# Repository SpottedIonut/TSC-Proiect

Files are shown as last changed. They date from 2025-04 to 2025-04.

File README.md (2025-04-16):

#### Spirchez Mihai 331CA
## Block Diagram
```mermaid
graph TD
  %% Center
  ESP[<span style='color:#e0ccff'><b>ESP32</b></span>]

  %% SPI Devices (Top)
  NOR[<span style='color:#ffcccc'>External NOR Flash</span>]
  EPD[<span style='color:#ffcccc'>E-Paper Display</span>]
  SD[<span style='color:#ffcccc'>SD Card</span>]

  NOR -->|SPI| ESP
  ESP -->|SPI| EPD
  SD -->|SPI| ESP

  %% I2C Devices (Bottom)
  RTC[<span style='color:#cce5ff'>RTC Module</span>]
  ENV[<span style='color:#cce5ff'>Environmental Sensor</span>]
  BCL[<span style='color:#cce5ff'>Battery Charge Level</span>]

  RTC -->|I2C| ESP
  ENV -->|I2C| ESP
  BCL -->|I2C| ESP

  %% Buttons (Left)
  BTN[<span style='color:#d4f4dd'>Buttons</span>]
  BTN --> ESP

  %% USB and Power (Right)
  USB[USB C Connector]
  CHG[Charging Controller]
  REG[Voltage Regulator]
  BATT[Battery]

  ESP -->|USB| USB
  USB --> CHG
  USB --> REG
  BATT --> CHG
  BATT --> REG

```
## Bill of Materials
|Component|Description|Purchase|Datasheet|
|---|---|---|---|
|EAGLE-LTSPICE_CC0402 | Capacitor | https://eu.mouser.com/ProductDetail/KEMET/C0402C475K8PACTU?qs=ulEaXIWI0c9ebKRT3r3htg%3D%3D | https://eu.mouser.com/datasheet/2/447/KEM_C1006_X5R_SMD-3316465.pdf
|ESP32_WROVER_EAGLE-LTSPICE_RR0402 | Resistor | https://eu.mouser.com/ProductDetail/Vishay-Beyschlag/MCS04020D9101BE000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  | https://www.vishay.com/docs/28700/mcx0x0xpre.pdf
|RCL_CPOL-EUCT3528 | Capacitor | https://eu.mouser.com/ProductDetail/Nichicon/LGN2W101MELA25?qs=Fe64Qgzkstf1zMszMsgRoA%3D%3D | https://eu.mouser.com/datasheet/2/293/e_lgn-3082370.pdf
|ADAFRUIT_LEDCHIP-LED0603 | LED | https://eu.mouser.com/ProductDetail/ams-OSRAM/KG-EELP41.22-PHRH-35-A8J8-20-R18?qs=ZcfC38r4Posajg8ZvCDQkg%3D%3D | https://eu.mouser.com/datasheet/2/588/KG_EELP41_22_EN-3572852.pdf
|CPH3225A | Capacitor | https://eu.mouser.com/ProductDetail/Seiko-Semiconductors/CPH3225A?qs=3etwrb1wR%252BhUOph6lAO7eg%3D%3D | https://eu.mouser.com/datasheet/2/360/Seiko_Instruments_MicroBattery_E_20230330_2024Jan_-3561061.pdf
|ESP32_WROVER_SPARKFUN-DISCRETESEMI_MOSFET_PCH-DMG2305UX-7 | Transistor | https://eu.mouser.com/ProductDetail/Diodes-Incorporated/DMG2305UX-7?qs=L1DZKBg7t5F%2FNBHrjfxC%252Bg%3D%3D | https://www.diodes.com/assets/Datasheets/DMG2305UX.pdf
|ESP32_WROVER_AVX---SD0805S020S1R0_AVX_SD0805S020S1R0_0_0AVX_SD0805S020S1R0_0_0 | Diode | https://eu.mouser.com/ProductDetail/ROHM-Semiconductor/SCS310AMC7G?qs=iLKYxzqNS75xiccEgNnX2g%3D%3D | https://fscdn.rohm.com/en/products/databook/datasheet/discrete/sic/sbd/scs310am-e.pdf
|SI1308EDL-T1-GE3 | Transistor | https://eu.mouser.com/ProductDetail/Vishay-Semiconductors/SI1308EDL-T1-GE3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 | https://www.vishay.com/docs/63399/si1308edl.pdf
|ESP32C6_VARISTORCN1812 | Varistor | https://eu.mouser.com/ProductDetail/Schurter/PFMF.050.2?qs=1auRipcfynCums5v1iucSA%3D%3D | https://eu.mouser.com/datasheet/2/358/typ_PFMF-1275918.pdf
|ESP32_WROVER_BME680_BME680 | Integrated Environmental Unit | https://eu.mouser.com/ProductDetail/M5Stack/U001-C?qs=e8oIoAS2J1R2mB7ZY1%252BSZg%3D%3D | https://docs.m5stack.com/en/unit/envIII
|ESP32-C6-WROOM-1-N8 | MicroController | https://eu.mouser.com/ProductDetail/Espressif-Systems/ESP32-C6?qs=Imq1NPwxi75noDtUpuVuWw%3D%3D | https://eu.mouser.com/datasheet/2/891/esp32_c6_datasheet_en-3304070.pdf
| 744043680IND_4828-WE-TPC_WRE | Inductor | https://eu.mouser.com/ProductDetail/Wurth-Elektronik/744043680?qs=PGXP4M47uW6VkZq%252BkzjrHA%3D%3D | https://www.we-online.com/components/products/datasheet/744043680.pdf
|SI1308EDL-T1-GE3 | Transistor | https://eu.mouser.com/ProductDetail/Vishay-Semiconductors/SI1308EDL-T1-GE3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 | https://www.vishay.com/docs/63399/si1308edl.pdf
| BD5229G-TR | Voltage Detector | https://eu.mouser.com/ProductDetail/ROHM-Semiconductor/BD5229G-TR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 | https://fscdn.rohm.com/en/products/databook/datasheet/ic/power/voltage_detector/bd52xxg-e.pdf
|DS3231SN# | RTC Module | https://eu.mouser.com/ProductDetail/Analog-Devices-Maxim-Integrated/DS3231SN?qs=1eQvB6Dk1vhUlr8%2FOrV0Fw%3D%3D | https://eu.mouser.com/datasheet/2/609/DS3231-3421123.pdf
|USBLC6-2SC6Y | ESD Protection | https://eu.mouser.com/ProductDetail/STMicroelectronics/USBLC6-2SC6Y?qs=gNDSiZmRJS%2FOgDexvXkdow%3D%3D | https://eu.mouser.com/datasheet/2/389/usblc6_2sc6y-1852505.pdf
|W25Q512JVEIQ | Flash Memory | https://eu.mouser.com/ProductDetail/Winbond/W25Q512JVEIQ?qs=l7cgNqFNU1jw6svr3at6tA%3D%3D | https://eu.mouser.com/datasheet/2/949/Winbond_W25Q512JV_Datasheet-3240039.pdf
|SAMACSYS_PARTS_USB4110-GF-A | USB Connector | https://eu.mouser.com/ProductDetail/GCT/USB4110-GF-A?qs=KUoIvG%2F9IlYiZvIXQjyJeA%3D%3D | https://eu.mouser.com/datasheet/2/837/GCT_USB4110_Product_Drawing___20k_cycles-3455479.pdf
|FH34SRJ | E-Paper Display Header | https://eu.mouser.com/ProductDetail/Hirose-Connector/FH34SRJ-7S-0.5SH50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 | https://eu.mouser.com/datasheet/2/185/FH34SRJ_7S_0_5SH_50__CL0580_1200_0_50_2DDrawing_00-1615127.pdf
|MAX17048G+T10 | Battery Management | https://eu.mouser.com/ProductDetail/Analog-Devices-Maxim-Integrated/MAX17048G%2bT10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 | https://eu.mouser.com/datasheet/2/609/MAX17048_MAX17049-3469099.pdf
|MCP73831 | Battery Controller | https://eu.mouser.com/ProductDetail/Microchip-Technology/MCP73831T-2ATI-MC?qs=yUQqVecv4qs9k7ug0bEXiw%3D%3D | https://eu.mouser.com/datasheet/2/268/MCP73831_Family_Data_Sheet_DS20001984H-3441711.pdf
|112A-TAAR-R03_ATTEND | SD Card Mount | https://store.comet.srl.ro/Catalogue/Product/43497/ | https://store.comet.srl.ro/Catalogue/Product/43497/
|XC6220A331MR-G | LDO Voltage Regulator | https://eu.mouser.com/ProductDetail/Torex-Semiconductor/XC6220A331MR-G?qs=AsjdqWjXhJ8ZSWznL1J0gg%3D%3D | https://eu.mouser.com/datasheet/2/760/xc6220-3371556.pdf

## Hardware components
- ESP32-C6-WROOM-1-N8 Microcontroller

### Communication interfaces

| Communication interface | Connected Components |
|---|---|
| I2C | RTC, BME688, Battery Level |
| SPI | SD Card, E-Paper Display, NOR Flash |
| USB | USB C Connector / Power |

### ESP32-C6-WROOM-1-N8 Pin Mapping

| ESP32 Pin | Signal | Purpose |
|---|---|---|
| IO0 | INT_RTC | RTC communication |
| IO1 | 32KHZ | RTC communication |
| IO2 | MISO | SD Card, NOR Flash |
| IO3 | EPD_BUSY | EPD status |
| IO4 | SS_SD | SD Card |
| IO5 | EPD_DC | EPD Data/Command |
| IO6 | SCK  | BME688, SD Card, NOR Flash |
| IO7 | MOSI | SD Card, NOR Flash, EPD |
| IO8 | GPIO8 | SD card select |
| IO9 | IO/BOOT | Boot button |
| IO10 | EPD_CS | EPD chip select|
| IO11 | FLASH_CS | NOR Flash chip select |
| IO12 | USB_D-| USB communication |
| IO13 | USB_D+ | USB communication |
| IO15 | IO/CHANGE | Button change |
| IO16 | TX | Transmit |
| IO17 | RX | Receive |
| IO18 | RTC_RST | RTC reset |
| IO19 | I2C_PW | BME688 power management |
| IO20 | EPD_3V3_C | EPD |
| IO21 | SDA | RTC, BME688, Battery Level (I2C data) |
| IO22 | SCL | RTC, BME688, Battery Level (I2C clock) |
| IO23 | EPD_RST | EPD reset |

- Real-Time Clock Module (RTC)
  - A DS3231SN RTC module
  - It communicates through I2C with the microcontroller
  - Pin connections:
      - SCL -> IO22
      - SDA -> IO21
      - RTC_RST -> IO18
      - 32KHZ -> IO1
      - INT_RTC -> IO0
- SD Card
  - It communicates through SPI
  - Pin connections:
    - MISO - IO2
    - SCK - IO6
    - MOSI - IO7
    - SS_SD - IO4
- E-Paper Display (EPD)
  - It communicates through SPI
  - Pin connections:
    - EPD_CS -> IO10
    - EPD_DC -> IO5
    - EPD_RST -> IO23
    - EPD_BUSY -> IO3
    - MOSI, SCK -> shared with SD
- Environmental Sensor
  - BME688 sensor
  - It communicates through I2C
  - Pin connections:
      - SCL -> IO22
      - SDA -> IO21
- Li-Po Battery Charging Controller
  - Battery Charge Level
    - It communicates through I2C
    - Pin connections:
        - SCL -> IO22
        - SDA -> IO21
- LDO Voltage Regulator
  - Lowers the 5V to 3.3V for the microcontroller and the attached modules
- SPI ESD Protection Lines
- NOR Flash 64MB
  - It communicates through SPI
  - Pin connections:
    - FLASH_CS -> IO11
    - SCK, MOSI, MISO
- USB
  - USB_D- -> IO12
  - USB_D+ -> IO13
- Buttons for user input
  - RESET -> EN
  - IO/BOOT -> IO9
  - IO/CHANGE -> IO15
- Qwiic / Stemma QT Connector
  - It communicates through I2C
  - SCL, SDA

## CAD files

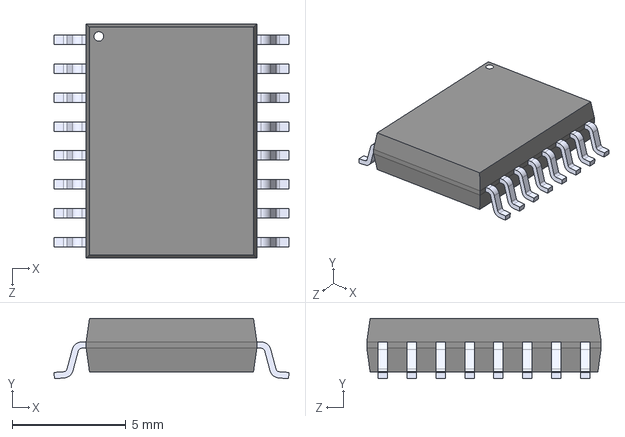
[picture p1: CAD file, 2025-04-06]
TSC/DS3231SN#.STEP
10.3 x 2.65 x 10.3 mm

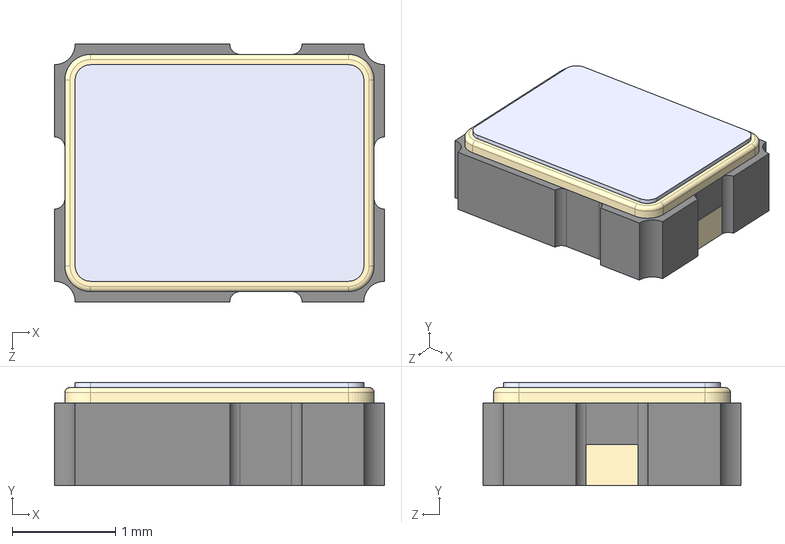
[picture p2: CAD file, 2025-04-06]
TSC/CPH3225A--3DModel-STEP-56544.STEP
3.20 x 1.00 x 2.50 mm

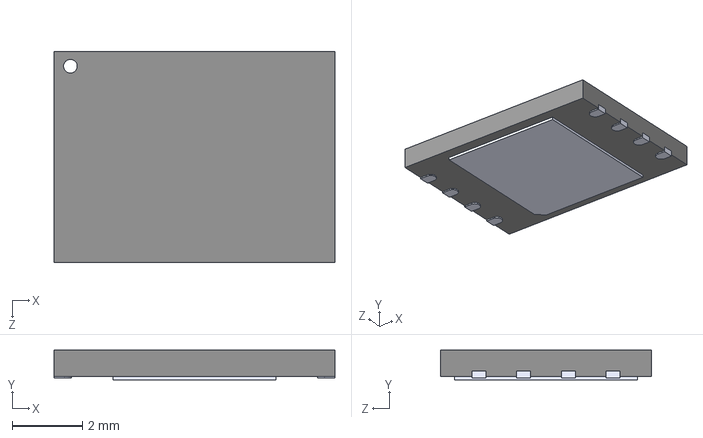
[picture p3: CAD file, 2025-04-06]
TSC/W25Q512JVEIQ--3DModel-STEP-269445.STEP
8.00 x 0.85 x 6.00 mm

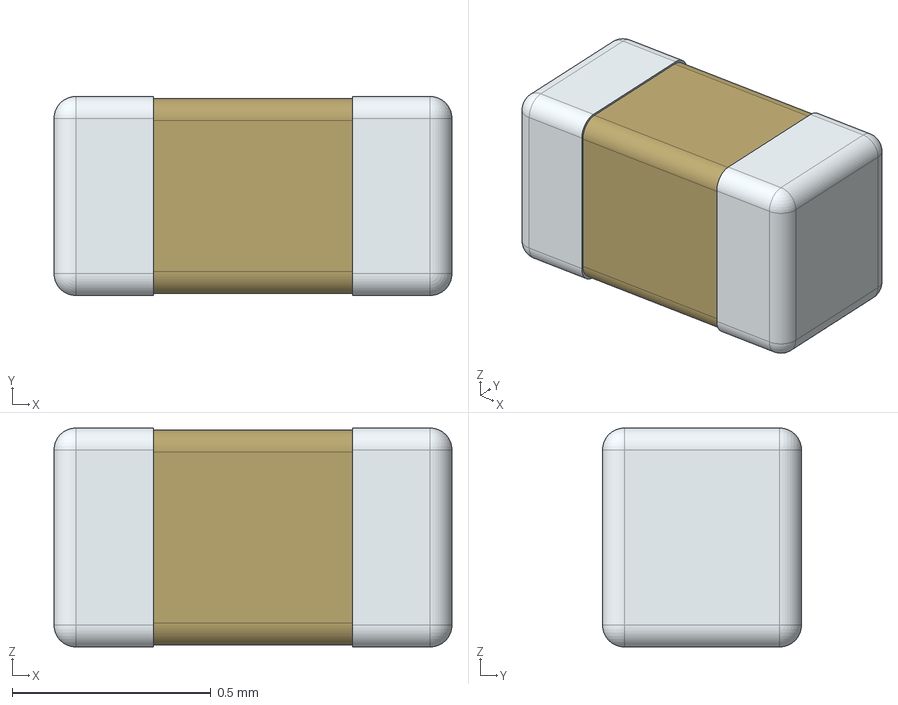
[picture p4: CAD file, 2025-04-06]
TSC/CC0402KRX5R6BB105.stp
1.00 x 0.5 x 0.55 mm

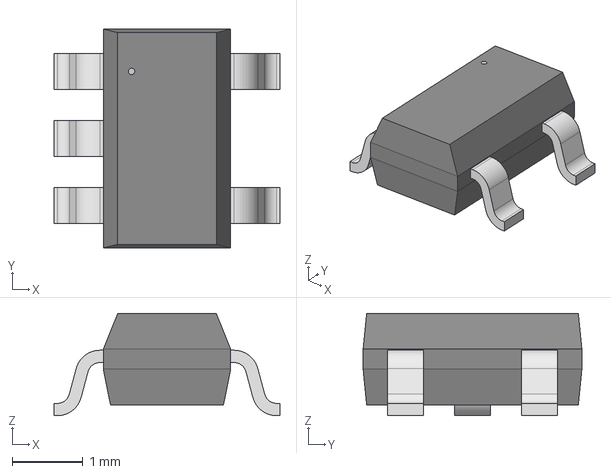
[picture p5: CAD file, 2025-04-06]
TSC/SOT-23-5_MC_MCH.step
3.20 x 3.10 x 1.45 mm

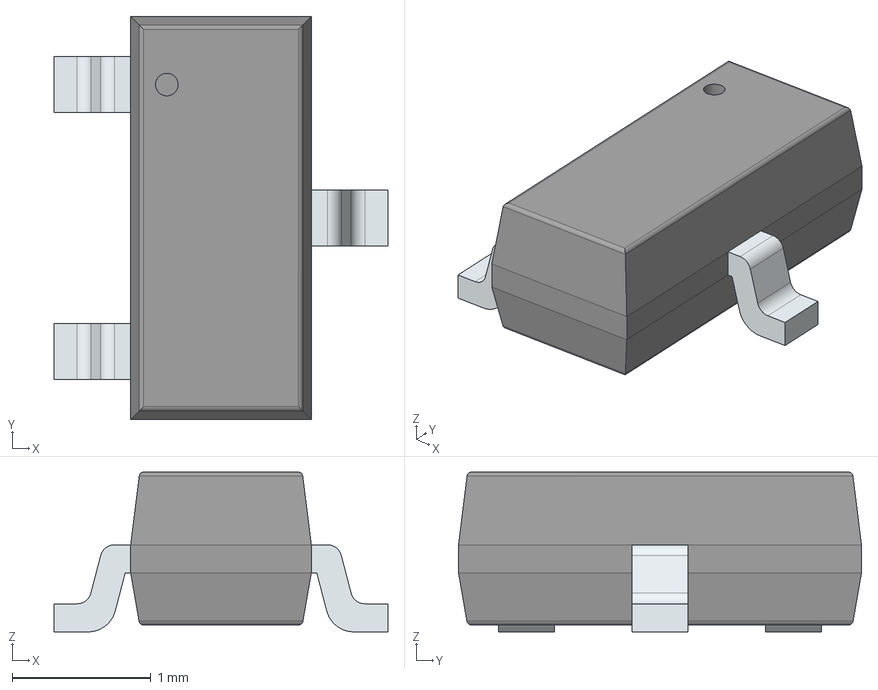
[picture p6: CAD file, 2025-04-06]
TSC/DMG2305UX-7.stp
2.40 x 2.90 x 1.15 mm
PinsArrayL
FilletPinR

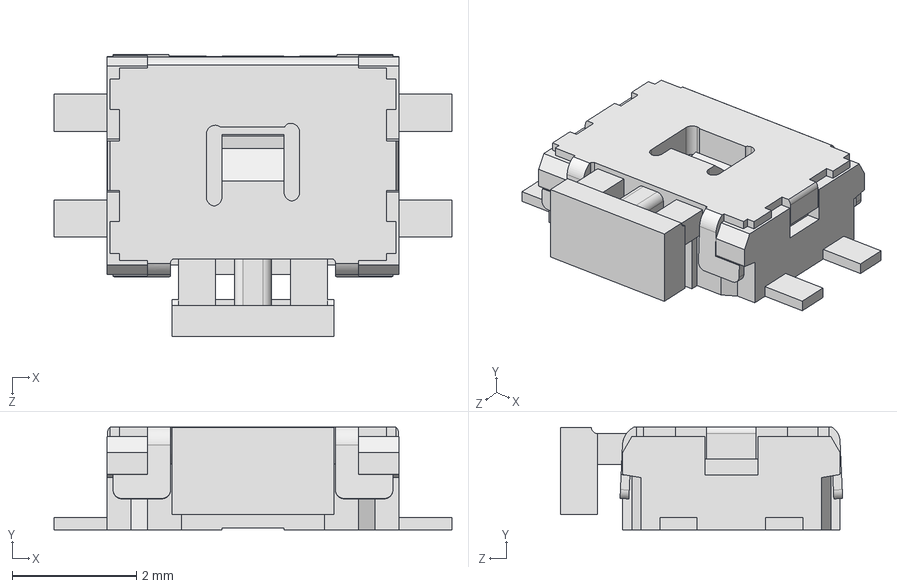
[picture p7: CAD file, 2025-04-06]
TSC/EVQPU-JA-02K.STEP
6.40 x 1.65 x 4.54 mm

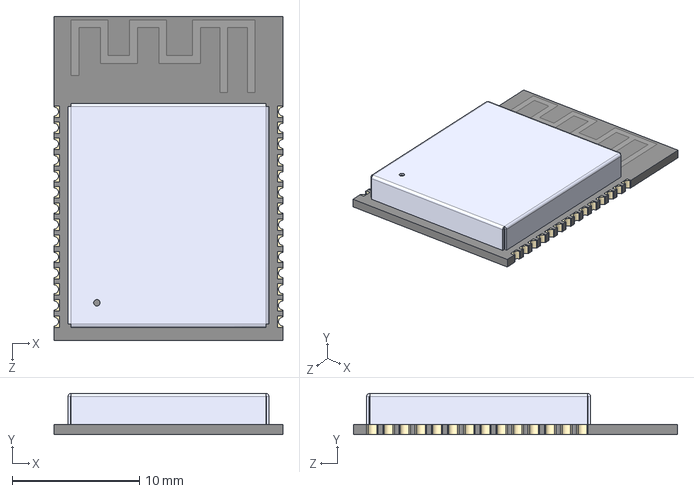
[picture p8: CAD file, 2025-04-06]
TSC/ESP32-C6-WROOM-1-N8--3DModel-STEP-56544.STEP
18.0 x 3.25 x 25.5 mm

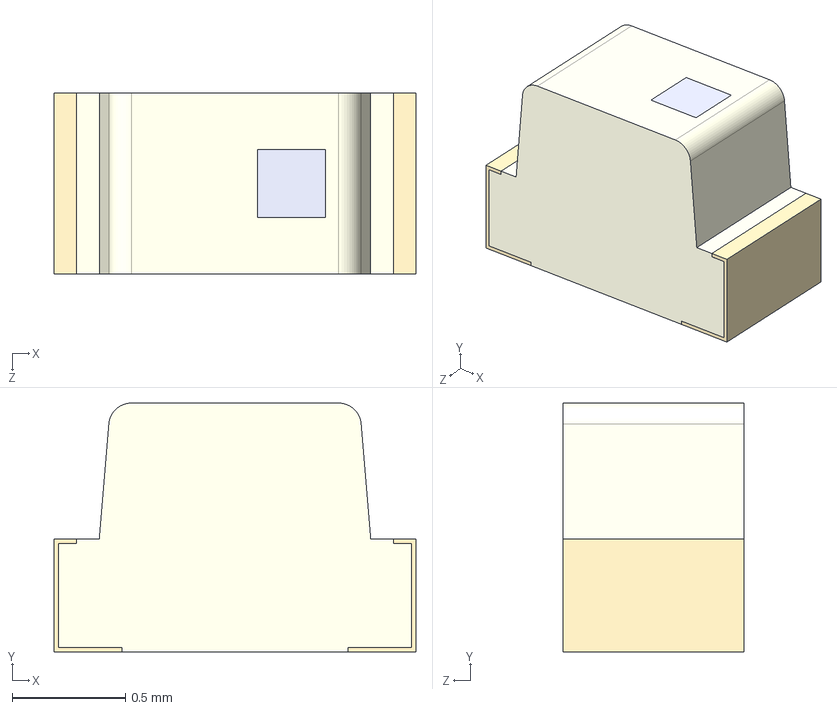
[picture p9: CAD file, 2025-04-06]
TSC/KP-1608SURCK.STEP
1.60 x 1.10 x 0.8 mm

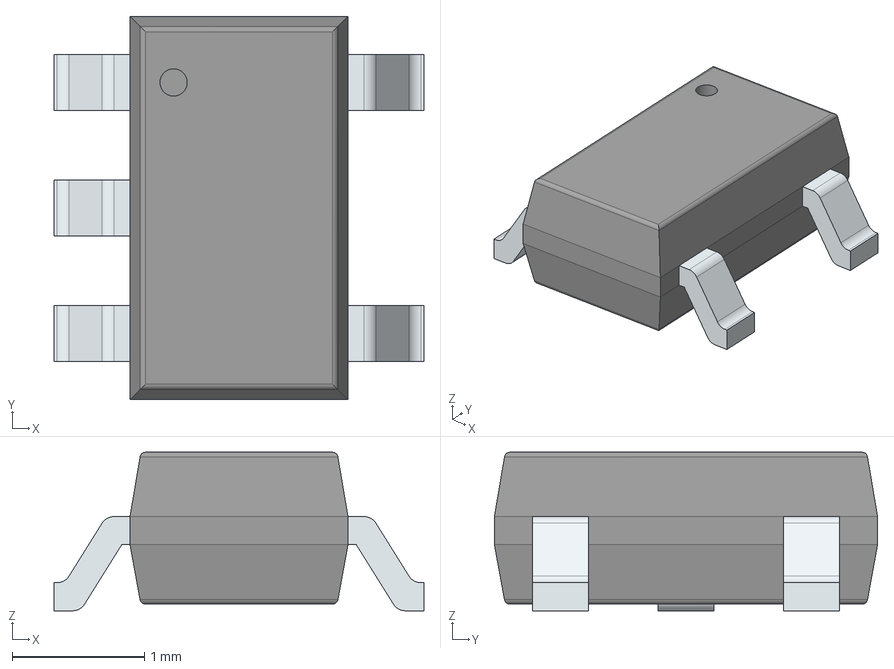
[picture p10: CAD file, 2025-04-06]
TSC/XC6220A331MR-G.stp
2.80 x 2.90 x 1.20 mm
PinsArrayL
PinsArrayR

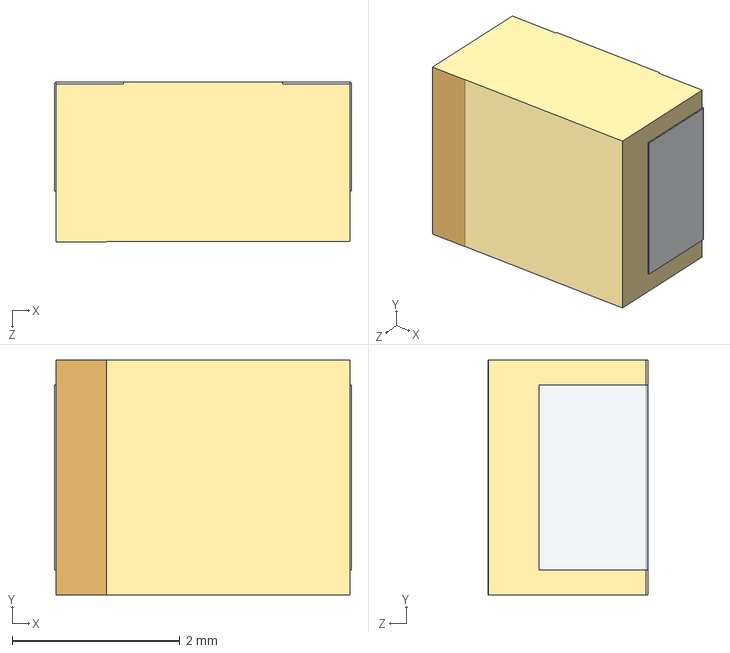
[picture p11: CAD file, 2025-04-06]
TSC/TANTALUM_B.STEP
3.54 x 2.80 x 1.91 mm

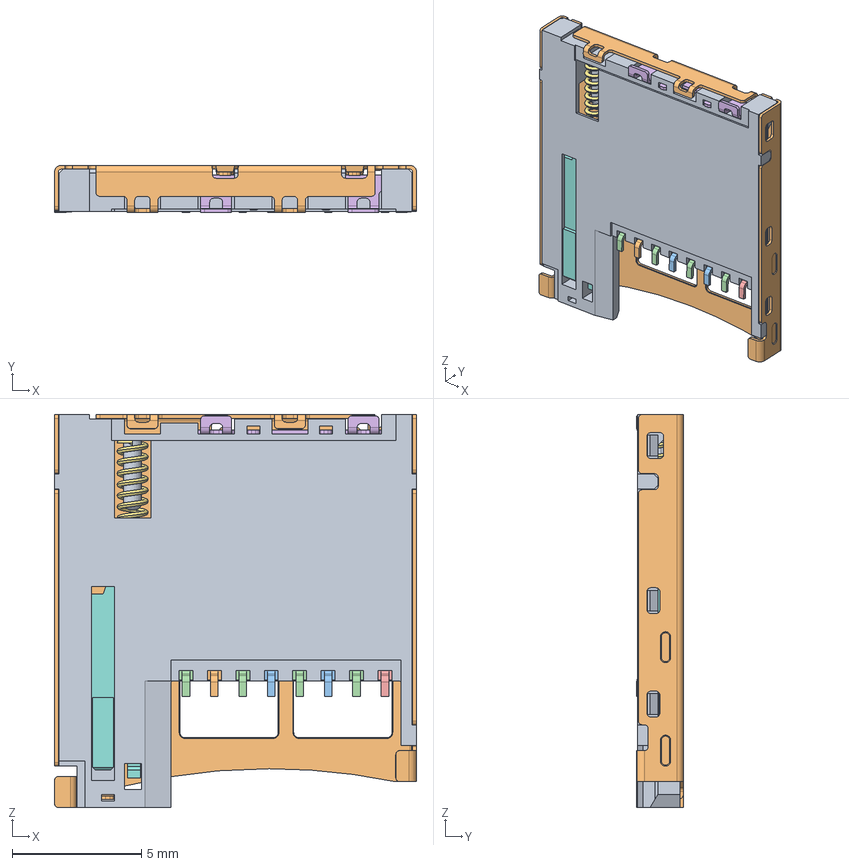
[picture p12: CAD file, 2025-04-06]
TSC/112A-TAAR-R02_C_1.stp
14.0 x 1.83 x 15.2 mm

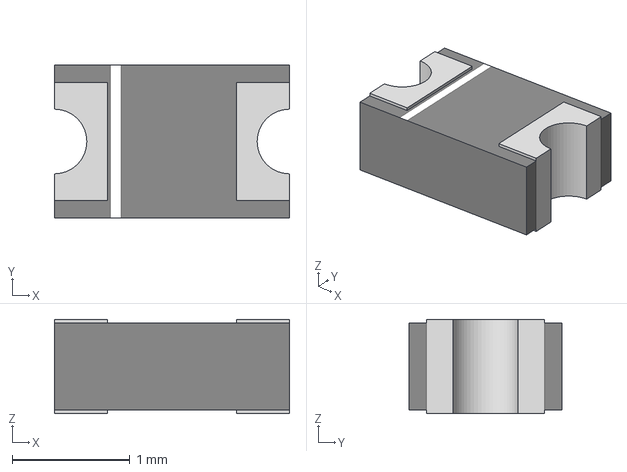
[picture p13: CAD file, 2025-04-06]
TSC/SD0805S020S1R0.stp
2.00 x 1.30 x 0.8 mm

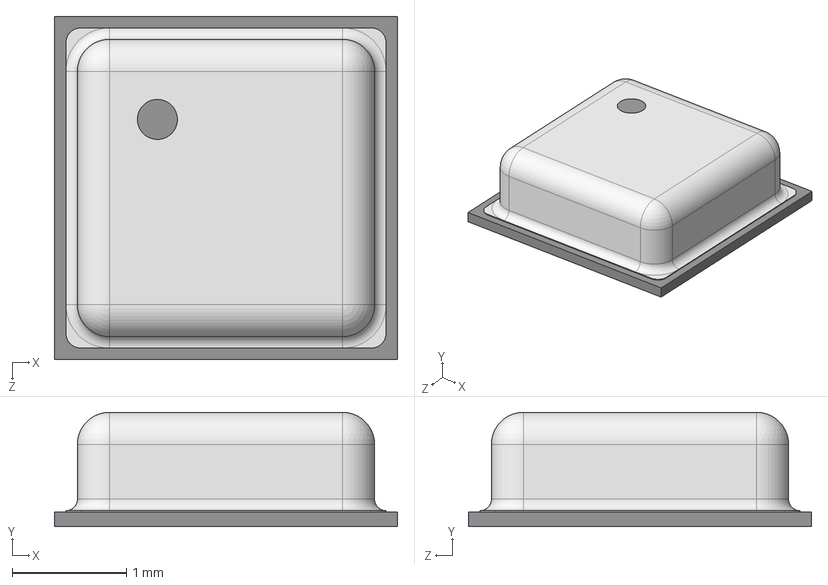
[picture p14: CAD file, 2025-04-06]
TSC/BME680--3DModel-STEP-510211.STEP
3.00 x 1.00 x 3.00 mm

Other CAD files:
TSC/BD5229G-TR.stp
TSC/USBLC6-2SC6Y.stp
TSC/Resistor_0402.step
TSC/PRT-14417.stp
TSC/744043680.stp
TSC/B72520T0350K062.stp
TSC/FH34SRJ-24S-0.5SH_99_.stp
TSC/LIB_744043680/744043680/Allegro/we-tpc_381692.psm
TSC/LIB_744043680/744043680/DEHDL/744043680/chips/chips.prt
TSC/MAX17048G-T10--3DModel-STEP-510211.STEP
TSC/MBR0530.STEP
TSC/MCP73831-2ATI_MC.stp
TSC/PGB1010603MR--3DModel-STEP-56544.STEP

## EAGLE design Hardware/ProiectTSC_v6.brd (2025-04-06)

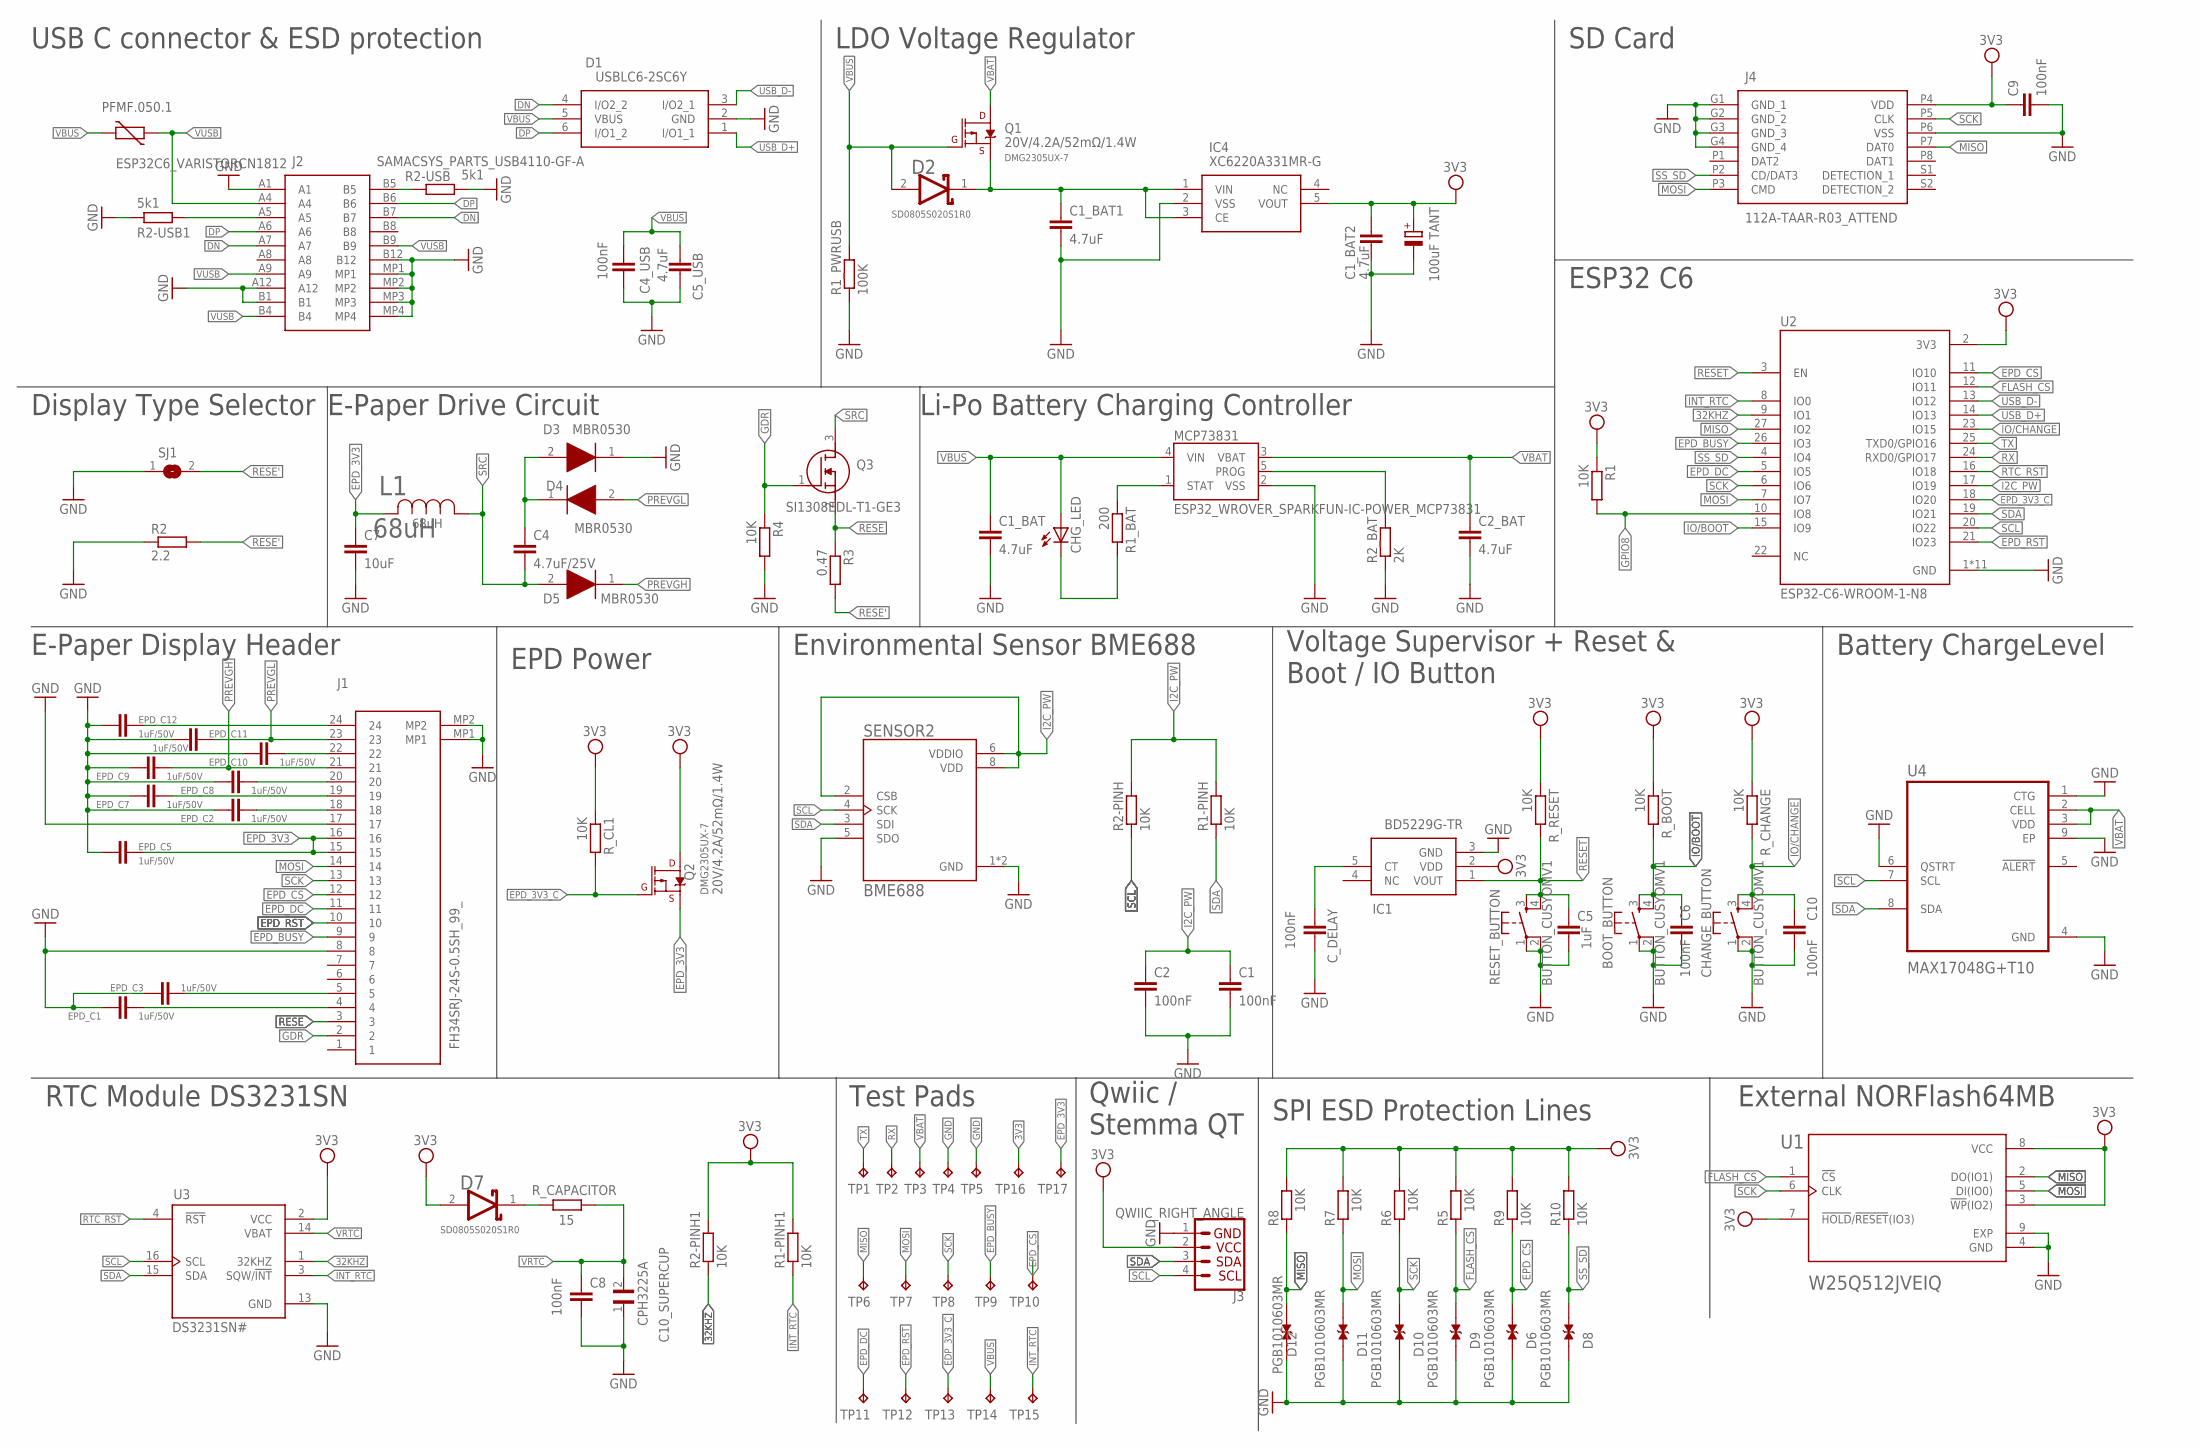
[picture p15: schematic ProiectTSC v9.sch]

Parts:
BOOT_BUTTON: BUTTON_CUSYOMV1; MYBUTTON
C1, C2, C4_USB, C6, C8, C9, C10: 100nF; EAGLE-LTSPICE_C0402
C1_BAT, C1_BAT1, C1_BAT2, C2_BAT, C5_USB: 4.7uF; EAGLE-LTSPICE_C0402
C4: 4.7uF/25V; EAGLE-LTSPICE_C0402
C5: 1uF; EAGLE-LTSPICE_C0402
C7: 10uF; EAGLE-LTSPICE_C0402
C10_SUPERCUP: CPH3225A; CAPCP3225X100N
CHANGE_BUTTON: BUTTON_CUSYOMV1; MYBUTTON
CHG_LED: ADAFRUIT_LEDCHIP-LED0603; ADAFRUIT_CHIP-LED0603
C_DELAY: 100nF; EAGLE-LTSPICE_C0402
D1: USBLC6-2SC6Y; SOT95P280X145-6N
D2, D7: SD0805S020S1R0; ESP32_WROVER_AVX---SD0805S020S1R0_AVX_SD0805S020S1R0_0
D3, D4, D5: MBR0530; SOD3716X135N
D6, D8, D9, D10, D11, D12: PGB1010603MR; DIOC1608X36N
EPD_C1, EPD_C2, EPD_C3, EPD_C5, EPD_C7, EPD_C8, EPD_C9, EPD_C10, EPD_C11, EPD_C12: 1uF/50V; EAGLE-LTSPICE_C0402
IC1: BD5229G-TR; SOT95P280X125-5N
IC4: XC6220A331MR-G; SOT95P280X120-5N
J1: FH34SRJ-24S-0.5SH_99_; FH34SRJ24S05SH99
J2: SAMACSYS_PARTS_USB4110-GF-A; SAMACSYS_PARTS_USB4110GFA
J3: QWIIC_RIGHT_ANGLE; JST04_1MM_RA
J4: 112A-TAAR-R03_ATTEND; 112ATAARR03ATTEND
L1: 68uH; IND_4828-WE-TPC_WRE
MCP73831: ESP32_WROVER_SPARKFUN-IC-POWER_MCP73831; ESP32_WROVER_SPARKFUN-IC-POWER_SOT23-5
PFMF.050.1: ESP32C6_VARISTORCN1812; ESP32C6_VARISTOR_CT/CN1812
Q1, Q2: 20V/4.2A/52mΩ/1.4W; ESP32_WROVER_SPARKFUN-DISCRETESEMI_SOT23-3
Q3: SI1308EDL-T1-GE3; SOT65P210X110-3N
R1, R1-PINH, R1-PINH1, R2-PINH, R2-PINH1, R4, R5, R6, R7, R8, R9, R10: 10K; ESP32_WROVER_EAGLE-LTSPICE_R0402
R1_BAT: 200; ESP32_WROVER_EAGLE-LTSPICE_R0402
R1_PWRUSB: 100K; ESP32_WROVER_EAGLE-LTSPICE_R0402
R2: 2.2; ESP32_WROVER_EAGLE-LTSPICE_R0402
R2-USB, R2-USB1: 5k1; ESP32_WROVER_EAGLE-LTSPICE_R0402
R2_BAT: 2K; ESP32_WROVER_EAGLE-LTSPICE_R0402
R3: 0.47; ESP32_WROVER_EAGLE-LTSPICE_R0402
RESET_BUTTON: BUTTON_CUSYOMV1; MYBUTTON
R_BOOT: 10K; ESP32_WROVER_EAGLE-LTSPICE_R0402
R_CAPACITOR: 15; ESP32_WROVER_EAGLE-LTSPICE_R0402
R_CHANGE: 10K; ESP32_WROVER_EAGLE-LTSPICE_R0402
R_CL1: 10K; ESP32_WROVER_EAGLE-LTSPICE_R0402
R_RESET: 10K; ESP32_WROVER_EAGLE-LTSPICE_R0402
SENSOR2: BME688; ESP32_WROVER_BME680_PSON80P300X300X100-8N
SJ1: SJ
TANT: 100uF; RCL_CT3528
TP1, TP2, TP3, TP4, TP5, TP6, TP7, TP8, TP9, TP10, TP11, TP12, TP13, TP14, TP15, TP16, TP17: TPTP20R; TP20R
U1: W25Q512JVEIQ; SON127P600X800X80-9N
U2: ESP32-C6-WROOM-1-N8; XCVR_ESP32-C6-WROOM-1-N8
U3: DS3231SN#; SOIC127P1032X265-16N
U4: MAX17048G+T10; SON50P200X200X80-9N

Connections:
3V3: C1_BAT2.1, C9.1, D7.2 (ANODE), IC1.2 (VDD), IC4.5 (VOUT), J3.2, J4.P4 (VDD), Q2.3 (D), R1.1, R1-PINH1.2, R2-PINH1.2, R5.2, R6.2, R7.2, R8.2, R9.2, R10.2, R_BOOT.1, R_CHANGE.1, R_CL1.1, R_RESET.1, TANT.+, TP16.TP, U1.3 (!WP!(IO2)), U1.7 (!HOLD!/!RESET!(IO3)), U1.8 (VCC), U2.2 (3V3), U3.2 (VCC)
32KHZ: R2-PINH1.1, U2.9 (IO1), U3.1 (32KHZ)
DN: D1.4 (I/O2_2), J2.A7, J2.B7
DP: D1.6 (I/O1_2), J2.A6, J2.B6
EDP_3V3_C: TP13.TP
EPD_3V3: C7.1, EPD_C5.1, J1.15, J1.16, L1.2, Q2.2 (S), TP17.TP
EPD_3V3_C: Q2.1 (G), R_CL1.2, U2.18 (IO20)
EPD_BUSY: J1.9, TP9.TP, U2.26 (IO3)
EPD_CS: D6.1, J1.12, R9.1, TP10.TP, U2.11 (IO10)
EPD_DC: J1.11, TP11.TP, U2.5 (IO5)
EPD_RST: J1.10, TP12.TP, U2.21 (IO23)
FLASH_CS: D9.1, R5.1, U1.1 (!CS), U2.12 (IO11)
GDR: J1.2, Q3.1 (G), R4.1
GND: BOOT_BUTTON.1, BOOT_BUTTON.2, C1.2, C1_BAT.2, C1_BAT1.2, C1_BAT2.2, C2.2, C2_BAT.2, C4_USB.2, C5.2, C5_USB.2, C6.2, C7.2, C8.2, C9.2, C10.2, C10_SUPERCUP.1, CHANGE_BUTTON.1, CHANGE_BUTTON.2, C_DELAY.2, D1.2 (GND), D3.1 (K), D6.2, D8.2, D9.2, D10.2, D11.2, D12.2, EPD_C1.2, EPD_C2.2, EPD_C3.2, EPD_C5.2, EPD_C7.2, EPD_C8.2, EPD_C9.2, EPD_C10.2, EPD_C11.2, EPD_C12.2, IC1.3 (GND), IC4.2 (VSS), J1.8, J1.17, J1.MP1, J1.MP2, J2.A1, J2.A12, J2.B1, J2.B12, J2.MP1, J2.MP2, J2.MP3, J2.MP4, J3.1, J4.G1 (GND_1), J4.G2 (GND_2), J4.G3 (GND_3), J4.G4 (GND_4), J4.P6 (VSS), MCP73831.2 (VSS), R1_PWRUSB.1, R2.1, R2-USB.2, R2-USB1.1, R2_BAT.1, R4.2, RESET_BUTTON.1, RESET_BUTTON.2, SENSOR2.1 (GND), SENSOR2.5 (SDO), SENSOR2.7 (GND), SJ1.1, TANT.-, TP4.TP, TP5.TP, U1.4 (GND), U1.9 (EXP), U2.1 (GND), U2.28 (GND), U2.29_1 (GND), U2.29_2 (GND), U2.29_3 (GND), U2.29_4 (GND), U2.29_5 (GND), U2.29_6 (GND), U2.29_7 (GND), U2.29_8 (GND), U2.29_9 (GND), U3.13 (GND), U4.1 (CTG), U4.4 (GND), U4.6 (QSTRT), U4.9 (EP)
GPIO8: R1.2, U2.10 (IO8)
I2C_PW: C1.1, C2.1, R1-PINH.2, R2-PINH.2, SENSOR2.2 (CSB), SENSOR2.6 (VDDIO), SENSOR2.8 (VDD), U2.17 (IO19)
INT_RTC: R1-PINH1.1, TP15.TP, U2.8 (IO0), U3.3 (SQW/!INT)
IO/BOOT: BOOT_BUTTON.3, BOOT_BUTTON.4, C6.1, R_BOOT.2, U2.15 (IO9)
IO/CHANGE: C10.1, CHANGE_BUTTON.3, CHANGE_BUTTON.4, R_CHANGE.2, U2.23 (IO15)
MISO: D12.1, J4.P7 (DAT0), R8.1, TP6.TP, U1.2 (DO(IO1)), U2.27 (IO2)
MOSI: D11.1, J1.14, J4.P3 (CMD), R7.1, TP7.TP, U1.5 (DI(IO0)), U2.7 (IO7)
unnamed: MCP73831.5 (PROG), R2_BAT.2
unnamed: J2.A5, R2-USB1.2
unnamed: MCP73831.1 (STAT), R1_BAT.1
unnamed: C4.1, D3.2 (A), D4.1 (K)
unnamed: C1_BAT1.1, D2.1 (CATHODE), IC4.1 (VIN), IC4.3 (CE), Q1.2 (S)
unnamed: CHG_LED.C, R1_BAT.2
unnamed: EPD_C12.1, J1.24
unnamed: J2.B5, R2-USB.1
unnamed: EPD_C10.1, J1.22
unnamed: C_DELAY.1, IC1.5 (CT)
unnamed: D7.1 (CATHODE), R_CAPACITOR.2
unnamed: EPD_C8.1, J1.20
unnamed: EPD_C7.1, J1.19
unnamed: EPD_C2.1, J1.18
unnamed: EPD_C1.1, J1.4
unnamed: EPD_C3.1, J1.5
PREVGH: D5.1 (K), EPD_C9.1, J1.21
PREVGL: D4.2 (A), EPD_C11.1, J1.23
RESE: J1.3, Q3.2 (S), R3.1
RESE': R2.2, R3.2, SJ1.2
RESET: C5.1, IC1.1 (VOUT), RESET_BUTTON.3, RESET_BUTTON.4, R_RESET.2, U2.3 (EN)
RTC_RST: U2.16 (IO18), U3.4 (!RST)
RX: TP2.TP, U2.24 (RXD0/GPIO17)
SCK: D10.1, J1.13, J4.P5 (CLK), R6.1, TP8.TP, U1.6 (CLK), U2.6 (IO6)
SCL: J3.4, R2-PINH.1, SENSOR2.4 (SCK), U2.20 (IO22), U3.16 (SCL), U4.7 (SCL)
SDA: J3.3, R1-PINH.1, SENSOR2.3 (SDI), U2.19 (IO21), U3.15 (SDA), U4.8 (SDA)
SRC: C4.2, D5.2 (A), L1.1, Q3.3 (D)
SS_SD: D8.1, J4.P2 (CD/DAT3), R10.1, U2.4 (IO4)
TX: TP1.TP, U2.25 (TXD0/GPIO16)
USB_D+: D1.1 (I/O1_1), U2.14 (IO13)
USB_D-: D1.3 (I/O2_1), U2.13 (IO12)
VBAT: C2_BAT.1, MCP73831.3 (VBAT), Q1.3 (D), TP3.TP, U4.2 (CELL), U4.3 (VDD)
VBUS: C1_BAT.1, C4_USB.1, C5_USB.1, CHG_LED.A, D1.5 (VBUS), D2.2 (ANODE), MCP73831.4 (VIN), PFMF.050.1.2, Q1.1 (G), R1_PWRUSB.2, TP14.TP
VRTC: C8.1, C10_SUPERCUP.2, R_CAPACITOR.1, U3.14 (VBAT)
VUSB: J2.A4, J2.A9, J2.B4, J2.B9, PFMF.050.1.1

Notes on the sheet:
USB C connector & ESD protection
LDO Voltage Regulator
SD Card
ESP32 C6
Display Type Selector
E-Paper Drive Circuit
Li-Po Battery Charging Controller
E-Paper Display Header
EPD Power
Environmental Sensor BME688
Voltage Supervisor + Reset & Boot / IO Button
Battery ChargeLevel
External NORFlash64MB
SPI ESD Protection Lines
Qwiic / Stemma QT
Test Pads
RTC Module DS3231SN

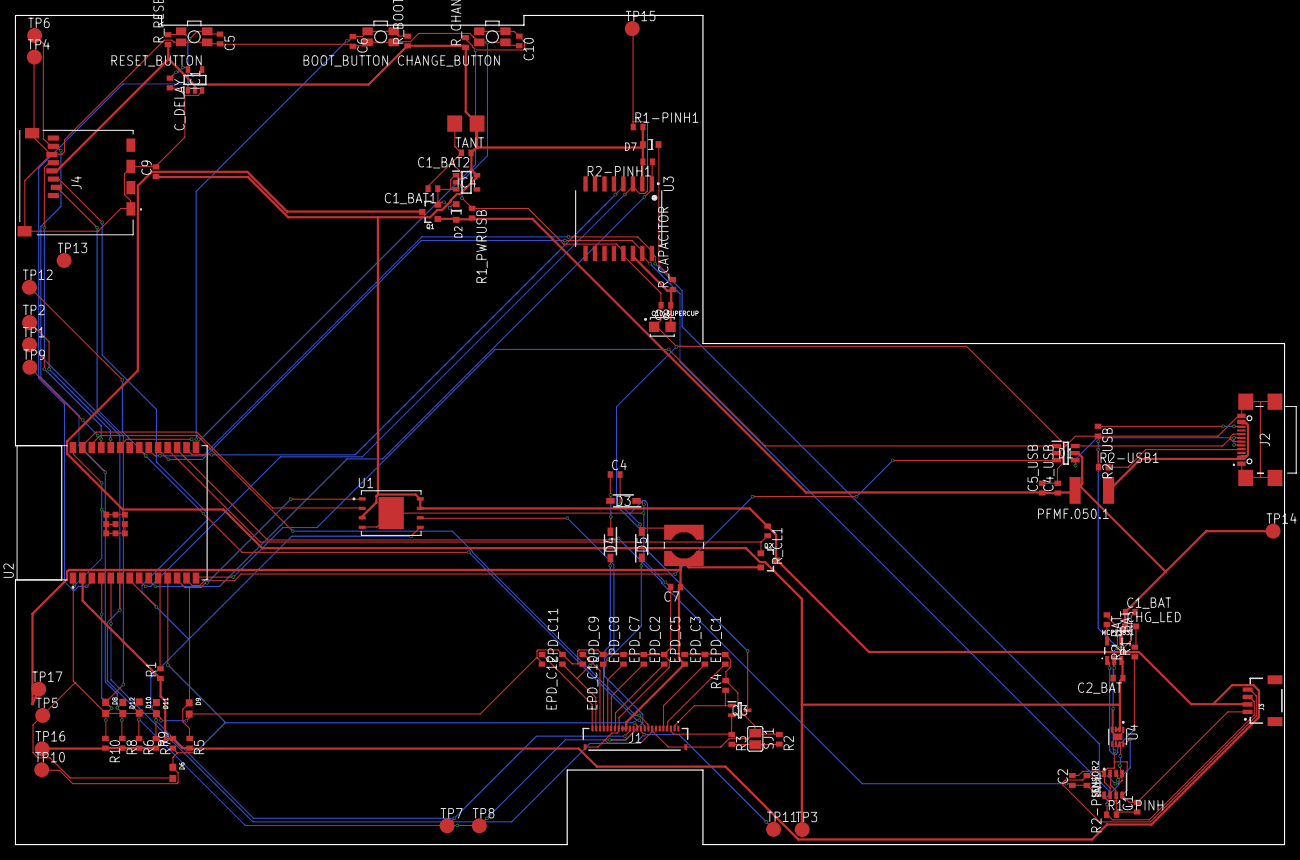
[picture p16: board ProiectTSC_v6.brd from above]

Board: 2 copper layers, 170.2 x 111.2 mm, 103 parts (0 on the bottom side), 55 nets.

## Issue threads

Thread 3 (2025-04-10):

Lipsa Via Stitching

iuliaandreea30, 2025-04-10:
Nu a fost aplicat Via Stitching intre cele doua planuri de masa, sugerez sa fie facut in apropierea modului ESP32, de asemenea poti sa-l faci de la Polygon in Fusion.

Closed 2025-04-15.

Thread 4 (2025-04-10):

Exploded View

iuliaandreea30, 2025-04-10:
Lipseste Exploded View (.step), acesta trebuie trimis alaturi de fisierul 3D cu dispozitivul complet si fisierul 3D Fusion care ar trebui sa se afle in directorul Mechanical.

Closed 2025-04-16.

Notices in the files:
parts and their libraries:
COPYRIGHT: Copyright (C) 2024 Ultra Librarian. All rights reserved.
